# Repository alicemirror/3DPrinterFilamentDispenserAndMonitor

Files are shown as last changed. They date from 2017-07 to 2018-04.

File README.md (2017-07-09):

# 3D Printer Filament Dispenser and Monitor
Communicates with your serial USB port with any USB connected device with this motorised version of the filament dispenser.

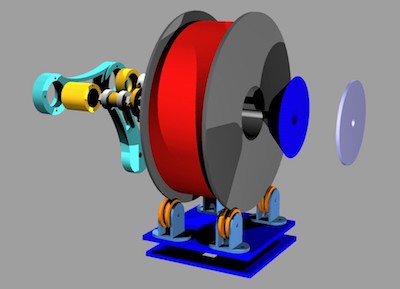
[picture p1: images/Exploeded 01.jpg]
3D render design


## Hardware
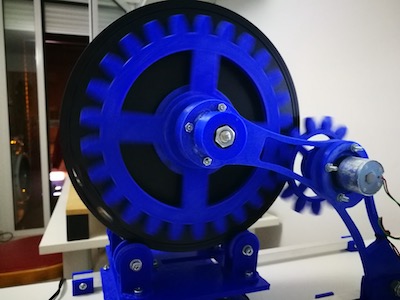
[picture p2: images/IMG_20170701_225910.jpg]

 
**_Micro Controller Platform_**: The _3D Printer filament dispenser_ software can work on [**Arduino**](http://export.farnell.com/arduino/a000066/atmega328-arduino-uno-eval-board/dp/2075382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) and the [**Infineon XMC 1100**](http://export.farnell.com/infineon/kit-xmc11-boot-001/cortex-m0-evaluation-board/dp/2376496) Arduino compatible board (that works better and faster).

**_DC Motor Shield_**: The DC motor is controlled by the **Infineon TLE97112LE** DC Motor controller shield for Arduino

**_Motor_**: Motion if actuated by a [**McLennan brushed DC Motor, DC 12 V**](http://export.farnell.com/mclennan/1271-12-10/motor-geared-12v-165rpm/dp/1784829)

**_Sensor_**: The weight sensor is a max 5Kg inexpensive load sensor connected to an AD amplifier board based on the **HX711** IC, specialised for load cells control.

**_Filament base_**: The filament base assemble the load cell sensor holding the MX711 AD filter acting as the support for the filament Roll. The base has four rotating bearings to reduce noise and friction.

Video: (https://www.youtube.com/watch?v=YBbqWqICec8)

## Application note
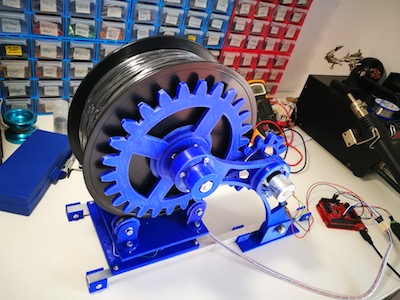
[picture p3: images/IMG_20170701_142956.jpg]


This software is also compatible with the non-motorised verson of the filament roll monitor and dispenser superseeding the previous version. To use the sketch without the motor just '<\#undef _USE_MOTOR>' in filament.h

# The system in action
Video: (https://www.youtube.com/watch?v=5b4c0GOEcK4)

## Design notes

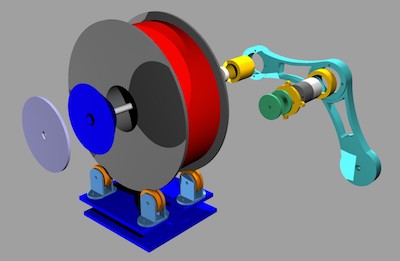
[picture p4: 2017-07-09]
images/Exploeded 02.jpg

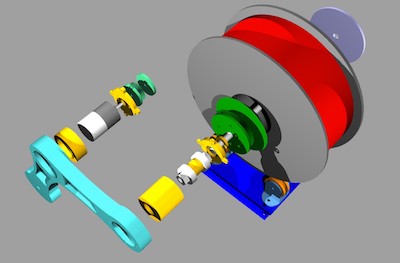
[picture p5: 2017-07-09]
images/Exploeded 04.jpg

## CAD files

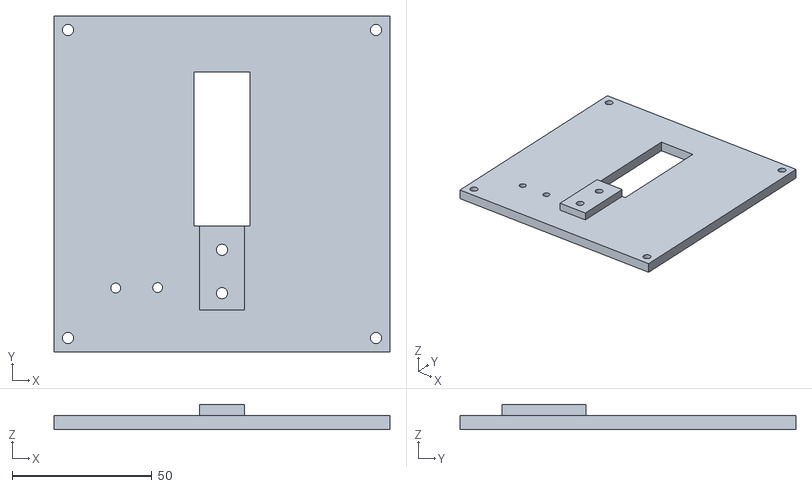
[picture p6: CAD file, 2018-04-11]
STL/ScaleBase.stl
120.0 x 120.0 x 9.00

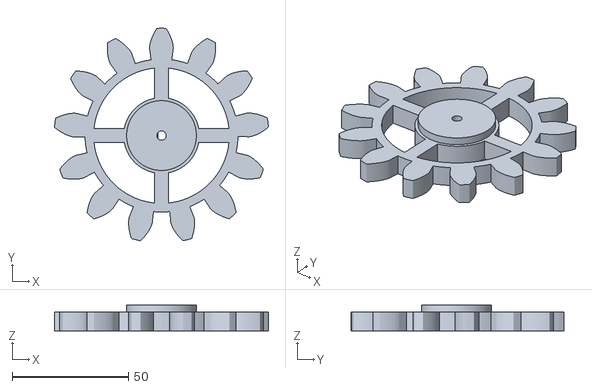
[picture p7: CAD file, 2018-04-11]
STL/MotorGear.stl
92.0 x 91.4 x 11.0

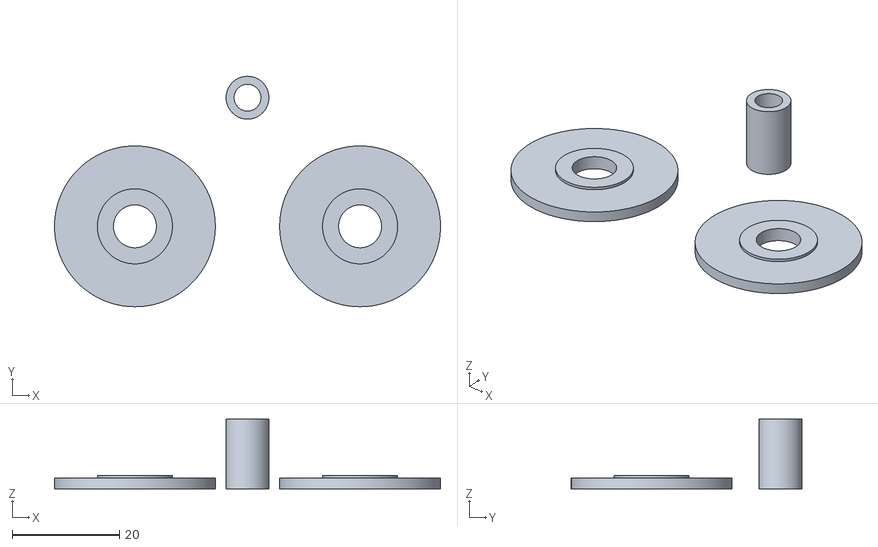
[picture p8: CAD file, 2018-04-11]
STL/ScalepartsBearing.stl
72.0 x 43.0 x 13.0

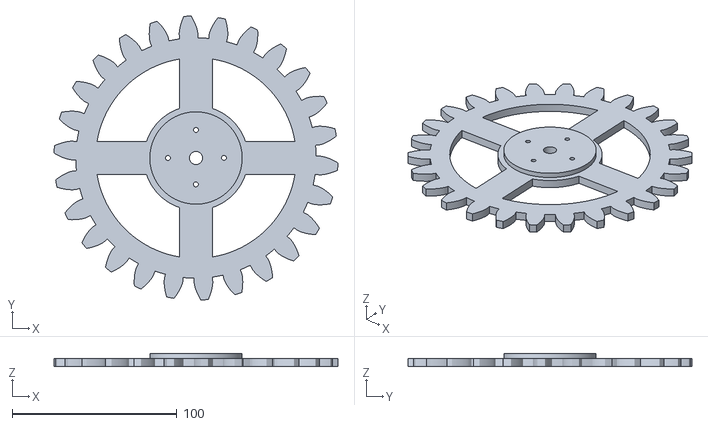
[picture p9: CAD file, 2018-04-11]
STL/RollGear.stl
172.2 x 172.2 x 8.00

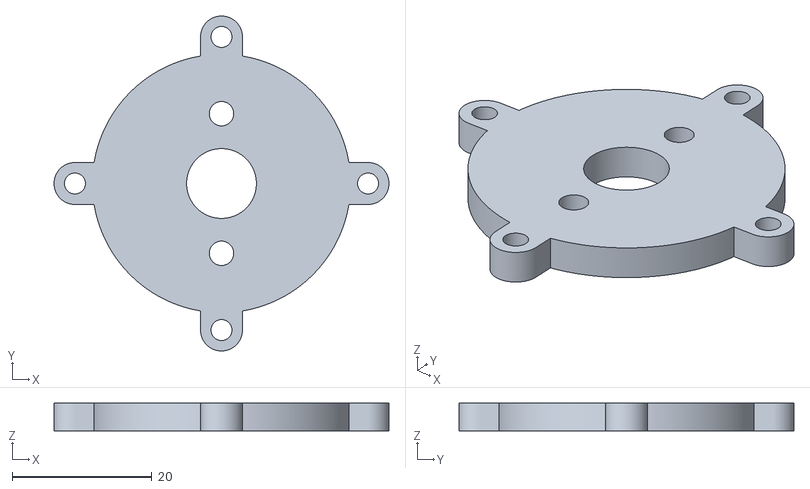
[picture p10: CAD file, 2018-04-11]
STL/Motor1.stl
48.0 x 48.0 x 4.00

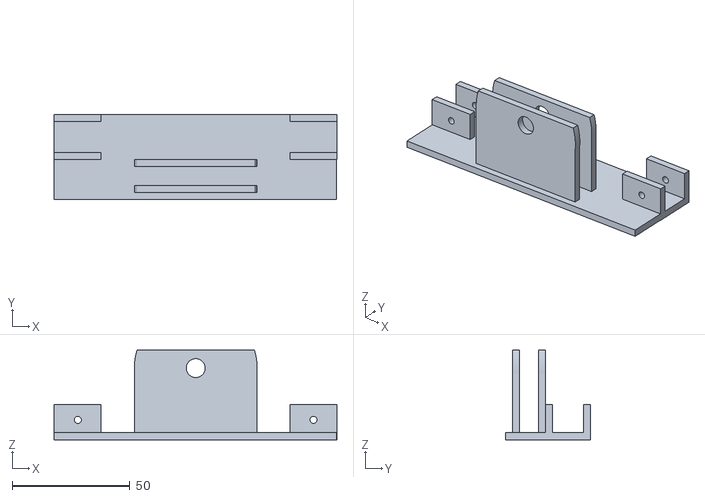
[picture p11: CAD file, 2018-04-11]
STL/Base Support 2.stl
120.0 x 36.0 x 38.0

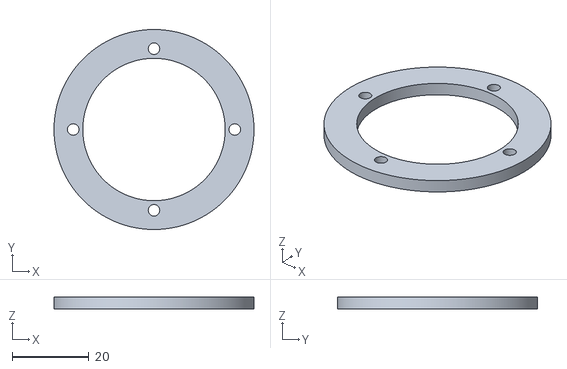
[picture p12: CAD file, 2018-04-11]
STL/MotionSupport3.stl
52.0 x 52.0 x 3.00

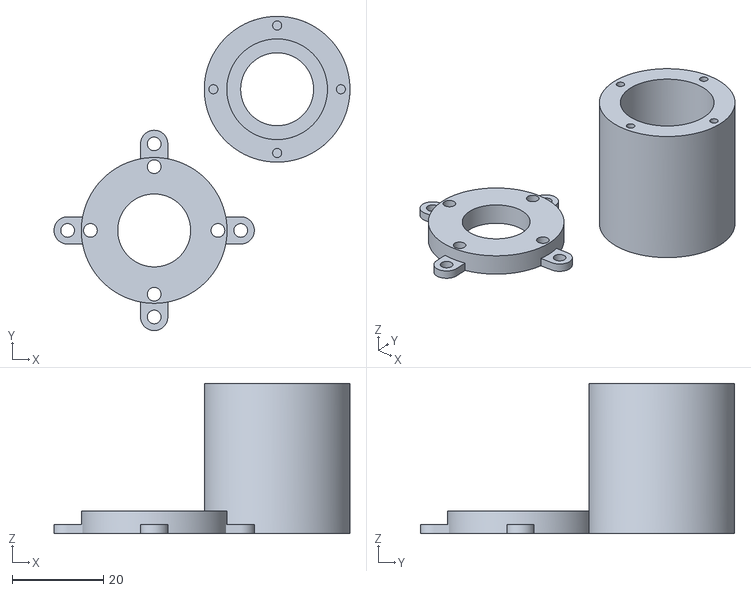
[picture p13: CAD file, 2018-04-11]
STL/BearingsBox.stl
65.0 x 69.0 x 33.0

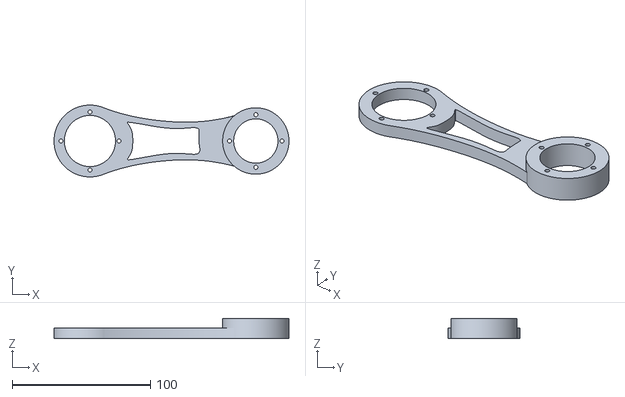
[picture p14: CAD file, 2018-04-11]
STL/MotionSupport1.stl
170.0 x 52.0 x 14.5

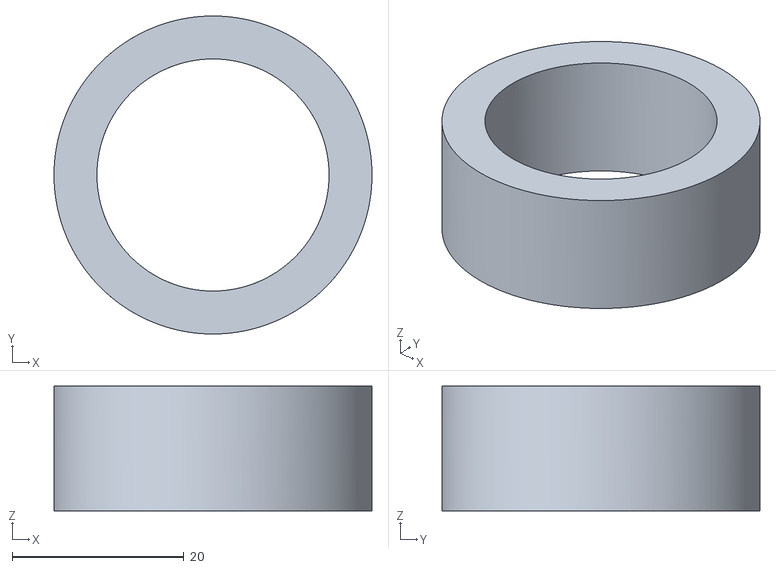
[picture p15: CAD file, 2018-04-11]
STL/Motor2.stl
37.0 x 37.0 x 14.5

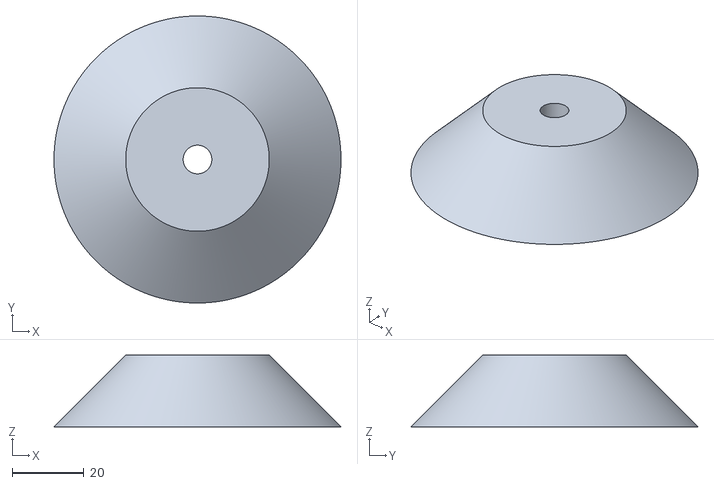
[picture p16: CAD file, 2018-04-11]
STL/RollMotorLock.stl
80.0 x 80.0 x 20.0

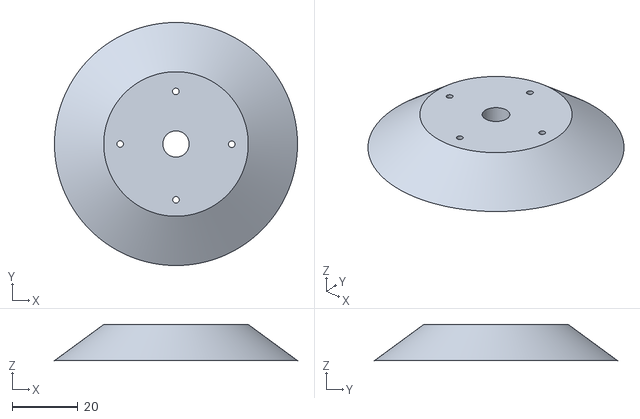
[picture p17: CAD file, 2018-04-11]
STL/RollMotorMove.stl
74.0 x 74.0 x 11.0

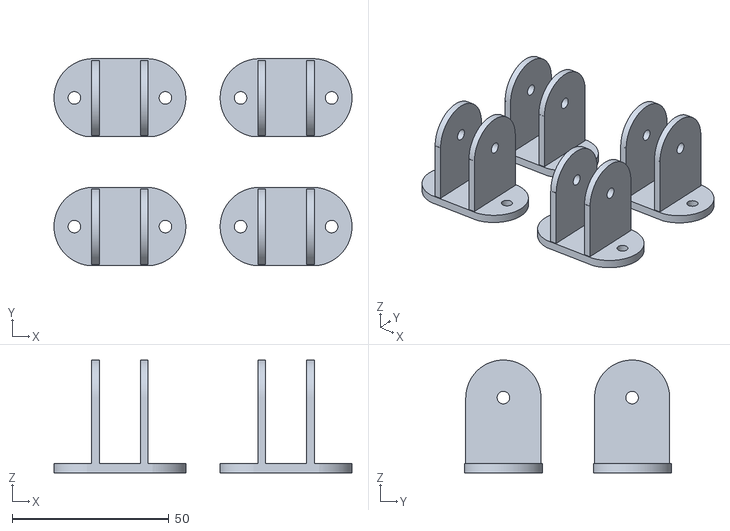
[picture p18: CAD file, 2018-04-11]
STL/RollSupport.stl
94.9 x 65.8 x 36.0

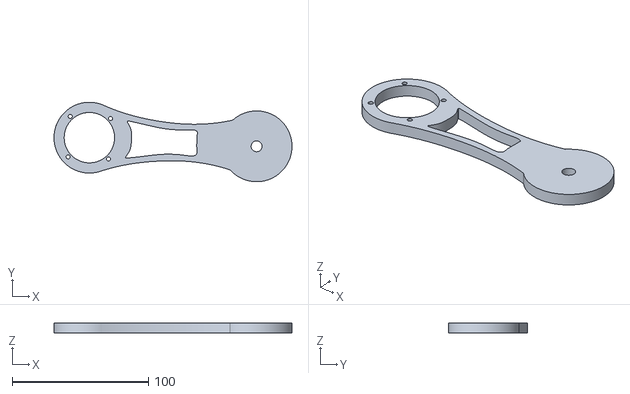
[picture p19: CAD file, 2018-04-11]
STL/MotionSupport2.stl
174.8 x 58.4 x 7.00

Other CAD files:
STL/ScalePlate.stl
STL/RollMotorSeparator.stl
STL/BearingsSeparator.stl
STL/RollMotorLockTop.stl

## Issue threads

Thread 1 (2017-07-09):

Weight data floating

alicemirror, 2017-07-09:
A moving average based on current and previous weighted calculation smoothing filter should be added as well as an excluding filter for totally out-of-range values.

Note(1): the data read while near to the filament pull event are already not collected.

Note(2): the experimental estimation of the acceptable range of sequential readings (fluctuations to be filtered) at the dte is 1.5 gr.

alicemirror, 2017-07-09:
Refer to the issue #1 to be analysed after a 3D printing job series for better practical solution (fast, efficient and now memory consuming)

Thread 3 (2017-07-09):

Command graph mode

alicemirror, 2017-07-09:
Add a "graph" command to plot real time the consumed and current remaining weight of filament using the Arduino IDE serial plot tool.

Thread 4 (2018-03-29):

stl file to print

titilecostaud, 2018-03-29:
Hello dear!

nice project. I desire to use it to reload filament correctly...

Is it possible to have scad or stl files to print 3D?

Thanks
thierrymoreaux@yahoo.fr

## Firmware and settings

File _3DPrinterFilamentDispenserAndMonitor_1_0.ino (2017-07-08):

/**

  3D Printer FIlament Dispense - USB to serial control

 The HX711 board can be powered from 2.7V to 5V so the Arduino 5V power should be fine.
 Thie is the motorised verion of the 3D printer filament monitor based on the Infineon brushed
 DC motor controller Arduino shield.
 The software has been developed on the Infineon XMC110 mciro controller board Arduino compatible

 *  \author Enrico Miglino <balearicdynamics@gmail.com> \n
 *  Balearic Dynamics sl <www.balearicdynamics.com> SPAIN
 *  \date July 2017
 *  \version 1.0 Release Candidate\n
 *  Licensed under GNU LGPL 3.0
*/

#include "filament.h"
#include "filamentweight.h"
#include "commands.h"
#ifdef _USE_MOTOR
#include "motorcontrol.h"
#endif

#ifdef _USE_MOTOR
MotorControl motor;
//! operating mode
boolean modeAuto;
#endif

//! The weight control class
FilamentWeight scale;

// ==============================================
// Initialisation
// ==============================================
void setup() {
  // Serial is initialised at high speed. If your Arduino boards
  // loose characters or show unwanted/unexpected behavior
  // try with a lower communication speed
  Serial.begin(38400);

  // Print the initialisation message
  Serial.println(APP_TITLE);

  // Initialize the weight class
  scale.begin();
#ifdef _USE_MOTOR
  // initialize the motor class
  motor.begin();  
  modeAuto = false;
#endif
}

// ==============================================
// Main loop
// ==============================================
/** 
 * The main loop role is execturing the service functions; display update, 
 * calculations, button checking
 * The scale reading is done at a specific frequence and is interrupt-driven
 */
void loop() {
  scale.readScale();

//  Serial.println(scale.lastRead);
  
#ifdef _USE_MOTOR
  // Check for the extruder request
  if( (scale.statID == STAT_RUN) && (scale.currentStatus.filamentNeededFromExtruder == true) ) {
    if(modeAuto) {
      motor.feedExtruder(FEED_EXTRUDER_DELAY);
      motor.tleDiagnostic();
    }
  }
#endif

  // Check if the motor is running to test the errors status
  if(motor.internalStatus.isRunning) {
    if(motor.tleCheckDiagnostic()) {
      motor.tleDiagnostic();
    }
  }

  if(Serial.available() > 0){
    parseCommand(Serial.readString());
  } // serial available
}

//! Send a single line message to the serial
void serialMessage(String title, String description) {
    Serial.print(title);
    Serial.print(" ");
    Serial.println(description);
}

/**
 * Parse the command string and echo the executing message or command unknown error.
 * 
 * \param commandString the string coming from the serial
 */
 void parseCommand(String commandString) {

  // =========================================================
  // Parameters settings
  // =========================================================

  // Set PLA material and recalculate the material characteristics
  // Flag is set to display an update nesxt loop cycle
  if(commandString.equals(SET_PLA)) {
    scale.materialID = PLA;
    scale.calcMaterialCharacteristics();
    scale.showInfo();
  }
  // Set ABS material and recalculate the material characteristics
  // Flag is set to display an update nesxt loop cycle
  else if(commandString.equals(SET_ABS)) {
    scale.materialID = ABS;
    scale.calcMaterialCharacteristics();
    scale.showInfo();
  }
  // Set 1.75 mm filament diameter and recalculate the material characteristics
  // Flag is set to display an update nesxt loop cycle
  else if(commandString.equals(SET_175)) {
    scale.diameterID = DIAM_175;
    scale.calcMaterialCharacteristics();
    scale.showInfo();
  }
  // Set 3.00 mm filament diameter and recalculate the material characteristics
  // Flag is set to display an update nesxt loop cycle
  else if(commandString.equals(SET_300)) {
    scale.diameterID = DIAM_300;
    scale.calcMaterialCharacteristics();
    scale.showInfo();
  }
  // Set 1kg filament spool and recalculate the material characteristics
  // Flag is set to display an update next loop cycle
  else if(commandString.equals(SET_1KG)) {
    scale.wID = ROLL1KG;
    scale.calcMaterialCharacteristics();
    scale.showInfo();
  }
  // Set 2kg filament spool and recalculate the material characteristics
  // Flag is set to display an update nesxt loop cycle
  else if(commandString.equals(SET_2KG)) {
    scale.wID = ROLL2KG;
    scale.calcMaterialCharacteristics();
    scale.showInfo();
  }
  // Set units in grams
  else if(commandString.equals(SET_WEIGHT)) {
    serialMessage(CMD_UNITS, commandString);
    scale.filamentUnits = _GR;
  }
  // Set units in cm
  else if(commandString.equals(SET_CENTIMETERS)) {
    serialMessage(CMD_UNITS, commandString);
    scale.filamentUnits = _CM;
  }

  // =========================================================
  // Change current functional status
  // =========================================================

  // Send a reset command and restore the parameters to the defaults
  // The tare is not recalculated to avoid wrong measure (if the spool
  // is already on the scale platform
  // This command had mandatory executi9on and ignore the previous state
  // The flag is set to show an update nextg loop cycle
  else if(commandString.equals(S_RESET)) {
    scale.reset();
    scale.stat = SYS_READY;
    scale.statID = STAT_READY;
//    scale.flashLED();
    scale.showInfo();
  }
  // Send a load command status setting
  // Should be executed after the filament roll has been set 
  // and placed on the scale base or after a reset command
  // The flag is set to show an update nextg loop cycle
  else if(commandString.equals(S_LOAD)) {
    scale.stat = SYS_LOAD;
    scale.statID = STAT_LOAD;
    scale.initialWeight = 0;
    scale.readScale();
    scale.showLoad();
  }
  // Send a run command status setting
  // Should be sent when a print job is started
  else if(commandString.equals(S_RUN)) {
    scale.stat = SYS_RUN;
    scale.statID = STAT_RUN;
    scale.initialWeight = scale.lastRead - scale.rollTare;
    scale.prevRead = scale.lastRead;
    scale.lastConsumedGrams = 0;
    scale.showStat();
  }
  // Send a default command status setting
  // Should be used to reset the system to the default values 
  // of the material without changing any setting in the weight
  // tare and calculations but the current status is not changed.
  // Use this commmand to reset the material to the internal conditions
  else if(commandString.equals(S_DEFAULT)) {
    scale.setDefaults();
    scale.showInfo();
  }  

  // =========================================================
  // Informative commands
  // =========================================================

  else if(commandString.equals(SHOW_INFO)) {
    scale.showInfo();
  }
  else if(commandString.equals(SHOW_STATUS)) {
    scale.showLoad();
    scale.showStat();
  }
  else if(commandString.equals(SHOW_DUMP)) {
    scale.showConfig();
  }
  else if(commandString.equals(SHOW_WEIGHT)) {
    Serial.print(CMD_WEIGHT);
    Serial.print(scale.getWeight());
    Serial.println(UNITS_GR);
  }

  // =========================================================
  // Motor control
  // =========================================================

#ifdef _USE_MOTOR
  else if(commandString.equals(MOTOR_FEED)) {
    serialMessage(CMD_EXEC, commandString);
    motor.feedExtruder(FEED_EXTRUDER_DELAY);
    motor.tleDiagnostic();
  }
  else if(commandString.equals(MOTOR_PULL)) {
    serialMessage(CMD_EXEC, commandString);
    motor.filamentLoad(FEED_EXTRUDER_DELAY);
    motor.tleDiagnostic();
  }
  else if(commandString.equals(MOTOR_STOP)) {
    serialMessage(CMD_EXEC, commandString);
    motor.motorBrake();
    motor.tleDiagnostic();
  }
  else if(commandString.equals(MOTOR_FEED_CONT)) {
    serialMessage(CMD_EXEC, commandString);
    motor.filamentContFeed();
  }
  else if(commandString.equals(MOTOR_PULL_CONT)) {
    serialMessage(CMD_EXEC, commandString);
    motor.filamentContLoad();
  }
#endif

  // =========================================================
  // Change behaviour mode
  // =========================================================

  else if(commandString.equals(MODE_AUTO)) {
    serialMessage(CMD_MODE, commandString);
    modeAuto = true;
  }
  else if(commandString.equals(MODE_MANUAL)) {
    serialMessage(CMD_MODE, commandString);
    modeAuto = false;
  }
  else
    serialMessage(CMD_WRONGCMD, commandString);
 }

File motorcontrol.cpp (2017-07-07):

/** 
 *  \file motorcontrol.cpp
 *  \brief This file defines functions and predefined instances from motorcontrol.h
 *  
 *  \author Enrico Miglino <balearicdynamics@gmail.com> \n
 *  Balearic Dynamics sl <www.balearicdynamics.com> SPAIN
 *  \date July 2017
 *  \version 1.0 Release Candidate
 *  Licensed under GNU LGPL 3.0
 */

#include "motorcontrol.h"

void MotorControl::begin(void) {
  // enable tle94112
  tle94112.begin();

  internalStatus.isRunning = false;

  // Disable the unused half bridges
  #ifdef _HIGHCURRENT
    // High current mode, keep in use HB1&2, 3&4
    tle94112.configHB(tle94112.TLE_HB5, tle94112.TLE_FLOATING, tle94112.TLE_NOPWM);
    tle94112.configHB(tle94112.TLE_HB6, tle94112.TLE_FLOATING, tle94112.TLE_NOPWM);
    tle94112.configHB(tle94112.TLE_HB7, tle94112.TLE_FLOATING, tle94112.TLE_NOPWM);
    tle94112.configHB(tle94112.TLE_HB8, tle94112.TLE_FLOATING, tle94112.TLE_NOPWM);
    tle94112.configHB(tle94112.TLE_HB9, tle94112.TLE_FLOATING, tle94112.TLE_NOPWM);
    tle94112.configHB(tle94112.TLE_HB10, tle94112.TLE_FLOATING, tle94112.TLE_NOPWM);
    tle94112.configHB(tle94112.TLE_HB11, tle94112.TLE_FLOATING, tle94112.TLE_NOPWM);
    tle94112.configHB(tle94112.TLE_HB12, tle94112.TLE_FLOATING, tle94112.TLE_NOPWM);
  #else
    // No High current mode use only HB1 & 2
    tle94112.configHB(tle94112.TLE_HB3, tle94112.TLE_FLOATING, tle94112.TLE_NOPWM);
    tle94112.configHB(tle94112.TLE_HB4, tle94112.TLE_FLOATING, tle94112.TLE_NOPWM);
    tle94112.configHB(tle94112.TLE_HB5, tle94112.TLE_FLOATING, tle94112.TLE_NOPWM);
    tle94112.configHB(tle94112.TLE_HB6, tle94112.TLE_FLOATING, tle94112.TLE_NOPWM);
    tle94112.configHB(tle94112.TLE_HB7, tle94112.TLE_FLOATING, tle94112.TLE_NOPWM);
    tle94112.configHB(tle94112.TLE_HB8, tle94112.TLE_FLOATING, tle94112.TLE_NOPWM);
    tle94112.configHB(tle94112.TLE_HB9, tle94112.TLE_FLOATING, tle94112.TLE_NOPWM);
    tle94112.configHB(tle94112.TLE_HB10, tle94112.TLE_FLOATING, tle94112.TLE_NOPWM);
    tle94112.configHB(tle94112.TLE_HB11, tle94112.TLE_FLOATING, tle94112.TLE_NOPWM);
    tle94112.configHB(tle94112.TLE_HB12, tle94112.TLE_FLOATING, tle94112.TLE_NOPWM);
  #endif
}

void MotorControl::end(void) {
  tle94112.end();
}

void MotorControl::feedExtruder(long duration) {
  motorRun(DC_MIN_EXTRUDER, DC_MAX_EXTRUDER, ACCELERATION_DELAY, duration, DIRECTION_FEED);
  motorBrake();
}

void MotorControl::filamentFeed(long duration) {
  motorRun(DC_MIN_MANUAL_FFED, DC_MAX_MANUAL_FFED, ACCELERATION_DELAY, duration, DIRECTION_FEED);
  motorBrake();
}

void MotorControl::filamentContFeed(void) {
  motorStart(DC_MIN_MANUAL_FFED, DC_MAX_MANUAL_FFED, ACCELERATION_DELAY, DIRECTION_FEED);
}

void MotorControl::filamentLoad(long duration) {
  motorRun(DC_MIN_MANUAL_LOAD, DC_MAX_MANUAL_LOAD, ACCELERATION_DELAY, duration, DIRECTION_LOAD);
  motorBrake();
}

void MotorControl::filamentContLoad(void) {
  motorStart(DC_MIN_MANUAL_FFED, DC_MAX_MANUAL_FFED, ACCELERATION_DELAY, DIRECTION_LOAD);
}

void MotorControl::motorRun(int minDC, int maxDC, int accdelay, long duration, int motorDirection) {
  int j;

  // If the motor is already running it is stopped before starting again
  if(internalStatus.isRunning)
    motorBrake();
  // Check for the direction
  if(motorDirection == DIRECTION_FEED) {
#ifdef _HIGHCURRENT
    tle94112.configHB(tle94112.TLE_HB1, tle94112.TLE_HIGH, tle94112.TLE_PWM1);
    tle94112.configHB(tle94112.TLE_HB2, tle94112.TLE_HIGH, tle94112.TLE_PWM1);
    tle94112.configHB(tle94112.TLE_HB3, tle94112.TLE_LOW, tle94112.TLE_NOPWM);
    tle94112.configHB(tle94112.TLE_HB4, tle94112.TLE_LOW, tle94112.TLE_NOPWM);
#else
    tle94112.configHB(tle94112.TLE_HB1, tle94112.TLE_HIGH, tle94112.TLE_PWM1);
    tle94112.configHB(tle94112.TLE_HB2, tle94112.TLE_LOW, tle94112.TLE_NOPWM);
#endif
  }
  else {
#ifdef _HIGHCURRENT
    tle94112.configHB(tle94112.TLE_HB1, tle94112.TLE_LOW, tle94112.TLE_NOPWM);
    tle94112.configHB(tle94112.TLE_HB2, tle94112.TLE_LOW, tle94112.TLE_NOPWM);
    tle94112.configHB(tle94112.TLE_HB3, tle94112.TLE_HIGH, tle94112.TLE_PWM1);
    tle94112.configHB(tle94112.TLE_HB4, tle94112.TLE_HIGH, tle94112.TLE_PWM1);
#else
    tle94112.configHB(tle94112.TLE_HB1, tle94112.TLE_LOW, tle94112.TLE_NOPWM);
    tle94112.configHB(tle94112.TLE_HB2, tle94112.TLE_HIGH, tle94112.TLE_PWM1);
#endif
  }

  // Acceleration loop  
  for(j = minDC; j <= maxDC; j++) {
    // Update the speed
    tle94112.configPWM(tle94112.TLE_PWM1, tle94112.TLE_FREQ200HZ, j);
  //Check for error
  if(tleCheckDiagnostic()) {
    tleDiagnostic();
  }
    delay(accdelay);
  }

  // Wait for the requeste number of ms at the regime speed
  tle94112.configPWM(tle94112.TLE_PWM1, tle94112.TLE_FREQ200HZ, maxDC);
  //Check for error
  if(tleCheckDiagnostic()) {
    tleDiagnostic();
  }
  delay(duration);

  // Deceleration loop  
  for(j = maxDC; j > minDC; j--) {
    // Update the speed
    tle94112.configPWM(tle94112.TLE_PWM1, tle94112.TLE_FREQ200HZ, j);
  //Check for error
  if(tleCheckDiagnostic()) {
    tleDiagnostic();
  }
    delay(accdelay);
  }
}

void MotorControl::motorStart(int minDC, int maxDC, int accdelay, int motorDirection) {
  int j;
  // If the motor is already running it is stopped before starting again
  if(internalStatus.isRunning)
    motorBrake();
  // Set the motor status
  internalStatus.isRunning = true;
  internalStatus.minDC = minDC;
  internalStatus.maxDC = maxDC;
  internalStatus.accdelay = accdelay;
  internalStatus.motorDirection = motorDirection;

  // Check for the direction
  if(motorDirection == DIRECTION_FEED) {
#ifdef _HIGHCURRENT
    tle94112.configHB(tle94112.TLE_HB1, tle94112.TLE_HIGH, tle94112.TLE_PWM1);
    tle94112.configHB(tle94112.TLE_HB2, tle94112.TLE_HIGH, tle94112.TLE_PWM1);
    tle94112.configHB(tle94112.TLE_HB3, tle94112.TLE_LOW, tle94112.TLE_NOPWM);
    tle94112.configHB(tle94112.TLE_HB4, tle94112.TLE_LOW, tle94112.TLE_NOPWM);
#else
    tle94112.configHB(tle94112.TLE_HB1, tle94112.TLE_HIGH, tle94112.TLE_PWM1);
    tle94112.configHB(tle94112.TLE_HB2, tle94112.TLE_LOW, tle94112.TLE_NOPWM);
#endif
  }
  else {
#ifdef _HIGHCURRENT
    tle94112.configHB(tle94112.TLE_HB1, tle94112.TLE_LOW, tle94112.TLE_NOPWM);
    tle94112.configHB(tle94112.TLE_HB2, tle94112.TLE_LOW, tle94112.TLE_NOPWM);
    tle94112.configHB(tle94112.TLE_HB3, tle94112.TLE_HIGH, tle94112.TLE_PWM1);
    tle94112.configHB(tle94112.TLE_HB4, tle94112.TLE_HIGH, tle94112.TLE_PWM1);
#else
    tle94112.configHB(tle94112.TLE_HB1, tle94112.TLE_LOW, tle94112.TLE_NOPWM);
    tle94112.configHB(tle94112.TLE_HB2, tle94112.TLE_HIGH, tle94112.TLE_PWM1);
#endif
  }

  // Acceleration loop  
  for(j = minDC; j <= maxDC; j++) {
    // Update the speed
    tle94112.configPWM(tle94112.TLE_PWM1, tle94112.TLE_FREQ200HZ, j);
    //Check for error
    if(tleCheckDiagnostic()) {
      tleDiagnostic();
    }
    delay(accdelay);
  }
  tle94112.configPWM(tle94112.TLE_PWM1, tle94112.TLE_FREQ200HZ, maxDC);
}
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

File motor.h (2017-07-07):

/* 
 *  \file motor.h
 *  \brief DC motor parameters for the Infineon DC motor controller Arduino shield
 *  TLE94112 from Infineon
 *  
 *  \author Enrico Miglino <balearicdynamics@gmail.com> \n
 *  Balearic Dynamics sl <www.balearicdynamics.com> SPAIN
 *  \date July 2017
 *  \version 1.0 Release Candidate
 *  Licensed under GNU LGPL 3.0
 */

#ifndef _MOTOR
#define _MOTOR

#include <TLE94112.h>

//! Duration in ms motor runs before reading for changes (sensor, serial)
#define MOTOR_PULSESHORT 100 
//! Duration in ms motor runs before reading for new command while motor
//! runs continuously
#define MOTOR_PULSELONG 500

//! Weight reading (grams) delta to start the motor running
//! requesting new filament released
#define FILAMENT_REQUEST 25

//! For high current coupling half bridges together 1&2, 3&4
#undef _HIGHCURRENT
#undef _MOTORDEBUG

//! Avoid too many openload error messages when starting acceleration
//! by default it is ignored
#define _IGNORE_OPENLOAD

// Duty cycles with PWM 200 Hz
#define DC_MIN_EXTRUDER 96        ///< Min duty cycle for acceleration on extruder request (auto feeding)
#define DC_MAX_EXTRUDER 160       ///< Max duty cycle for acceleration on extruder request (auto feeding)
#define DC_MIN_MANUAL_FFED 96     ///< Min duty cycle for acceleration on manual feeding
#define DC_MAX_MANUAL_FFED 255    ///< Max duty cycle for acceleration on manual feeding
#define DC_MIN_MANUAL_LOAD 128    ///< Min duty cycle for acceleration on manual loading
#define DC_MAX_MANUAL_LOAD 255    ///< Max duty cycle for acceleration on manual loading

#define INVERT_DIRECTION_DELAY 300  ///< Delay in ms when the motor should invert direction
#define ACCELERATION_DELAY 5        ///< Delay between acceleration steps
#define FEED_EXTRUDER_DELAY 1500    ///< Delay ms for an Extruder feed unit (time related to filament feed length)

#define DIRECTION_FEED 1    ///< Motor rotates to release filament
#define DIRECTION_LOAD 2    ///< Motor rotates to load filament

#ifdef _HIGHCURRENT
//! High current error title
#define TLE_ERROR_MSG "TLE94112 HC Error"
#else
//! Error title
#define TLE_ERROR_MSG "TLE94112 Error"
#endif
#define TLE_NOERROR "No Error"
#define TLE_SPIERROR "SPI"
#define TLE_LOADERROR "Open"
#define TLE_UNDERVOLTAGE "Under V"
#define TLE_OVERVOLTAGE "Over V"
#define TLE_POWERONRESET "Pwr rst" 
#define TLE_TEMPSHUTDOWN "Temp shutdown"
#define TLE_TEMPWARNING "Warn high temp"

#endif

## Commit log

2017-07-01 Constants definition
    Defined motor constants and serial commands (verbose)
2017-07-02 Motor control
    Added MotorControl class and connected to the main application.
2017-07-02 Added FilamentWeight class
2017-07-03 Implemented the setting commands and motor control
    #Issue : review all the motor commands for complete behaviour.
    MotorControl class should be updated
    [_3DPrinterFilamentDispenserAndMonitor_1_0.ino, commands.h, filament.h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]
2017-07-04 MotrControl class update
    Set the full working brake method
    Enabled the feed and pull continuous commands
    Set correctly the running status in all possible cases
    [_3DPrinterFilamentDispenserAndMonitor_1_0.ino, motor.h, motorcontrol.cpp]
2017-07-04 Updates on Parser and Serial usage
    Implemented the WeightFilament::Calibration method that works only in a
    separate sketch
    Removed the usage of the Streaming class
    Updated the serial output with Serial.print[ln]() methods
2017-07-05 Added the calibration sketch
2017-07-06 Updated stat() method
    Corrected the show consumed grams / cm value
    [filamentweight.cpp]
2017-07-07 Refined the calculation algorithmg
    Reviewed the status change (LOAD/RUN)
    Eliminated the issue in the RUN mode (inifinite feed loop)
    Cleaned code and reduced heap space
    Optimised commands
    [_3DPrinterFilamentDispenserAndMonitor_1_0.ino, commands.h, filament.h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]
2017-07-08 Version 1.0.20 Final Release
    Issue: set the correct values when starting and loading for remaining
    filament
    Updated the status and config methods calculations
    [_3DPrinterFilamentDispenserAndMonitor_1_0.ino, filament.h, filamentweight.cpp]
2017-07-19 Bug fixing
    Added the _INFINEON_BOARD define in motorcontrol.h for the issue
    workaround in the TLE94112 Arduino library by Infineon
    [filament.h]
2018-04-11 Added the 3D printable STL files
    [Base Support 2.stl, BearingsBox.stl, BearingsSeparator.stl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]
